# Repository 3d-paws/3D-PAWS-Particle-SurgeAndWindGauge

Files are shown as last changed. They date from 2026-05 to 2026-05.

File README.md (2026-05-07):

# Storm Surge Wind Gauge (SSWG)

### Storm Surge

The station used the below storm surge calculation.

#### 3 minute water level average
181 one-second water level samples are centered at (0,6,12,18,24,30,36,42,48,54). These samples are averaged, 
a three standard deviation outlier rejection test applied, 
the mean and standard deviation are recalculated and reported along with the number of outliers.

We can use the 181 observations to capture the mean and standard deviation and then multiply the value by 3. 

Reference:  https://tidesandcurrents.noaa.gov/publications/CO-OPS_Measurement_Spec.pdf

Add 90 seconds after each (0,6,12,18,24,30,36,42,48,54) sample period for the reported time.

#### To calculate the standard deviation of those numbers:

 - Work out the Mean (the simple average of the numbers)
 - Then for each number: subtract the Mean and square the result.
 - Then work out the mean of those squared differences.
 - Take the square root of that and we are done!

#### A sigma value is a statistical term otherwise known as a standard deviation. The three-sigma process:

 - 1 Calculate the mean
 - 2 Calculate the standard deviation
 - 3 Multiply the standard deviation by 3
 - 4 Subtract the product in step 3 from the mean

#### Distance Sensors

 - The 5-meter sensors (MB7360, MB7369, MB7380, and MB7389) use a scale factor of (Vcc/5120) per 1-mm. Particle 12bit resolution (0-4095),  Sensor has a resolution of 0 - 5119mm,  Each unit of the 0-4095 resolution is 1.25mm

 - The 10-meter sensors (MB7363, MB7366, MB7383, and MB7386) use a scale factor of (Vcc/10240) per 1-mm. Particle 12bit resolution (0-4095),  Sensor has a resolution of 0 - 10239mm,  Each unit of the 0-4095 resolution is 2.5mm

### Wind Support

Wind is enabled by default. Meaning you should add a AS5600 for direction readings. Or disable able wind with NOWIND.TXT file.

### Sensor Support
| Sensor Model | Type | Description | Company URL |
|---|---|---|---|
| Adafruit HTU21DF | Temp/Humidity | Digital I2C sensor, ±2% RH, ±0.3°C, compact, low power. | [Adafruit HTU21DF](https://www.adafruit.com/product/1899) |
| Adafruit MCP9808 | Temperature | High-precision digital temp sensor, ±0.25°C, 2.7-5.5V, I2C. | [Adafruit MCP9808](https://www.adafruit.com/product/1782) |
| Adafruit BME280 | Temp/Humidity/Pressure  | Measures temp, humidity, pressure, I2C/SPI, -40 to +85°C, 0-100% RH, 1.8-5V. | [Adafruit BME280](https://www.adafruit.com/product/2652) |
| Adafruit BMP280 | Temp/Pressure | Measures pressure (300–1100 hPa), temperature, I2C/SPI, small, low-power. | [Adafruit BMP280](https://www.adafruit.com/product/2651) |
| Adafruit BMP3XX | Temp/Pressure | Gen3 barometric, high-precision, ±0.5m alt., I2C/SPI. | [BMP388/BMP3XX](https://shop.pimoroni.com/en-us/products/adafruit-bmp388-precision-barometric-pressure-and-altimeter) |
| Adafruit_BMP5xx | Temp/Pressure | BMP5xx series (BMP581) is a high-precision barometric pressure sensors from Bosch Sensortec | [Adafruit BMP5xx](hhttps://www.adafruit.com/product/6407) |
| Adafruit SHT31 | Temp/Humidity | High accuracy, ±2% RH, ±0.3°C, I2C, fast response, 2.4–5.5V. | [Adafruit SHT31](https://www.adafruit.com/product/2857) |
| Adafruit_SHT4x | Temp/Humidity | Adafruit Sensirion SHT45 Precision Temp & Humidity with PTFE | [Adafruit SHT45](https://www.adafruit.com/product/5665) |
| Adafruit PM25AQI | PM2.5 Air Quality | Measures particulate (0.3–10um), I2C (fixed 0x12), 0-500μg/m³ range, 5V. | [PM25AQI](https://www.adafruit.com/product/4632) |
| AS5600L | Magnetic Encoder | Same as AS5600, but designed for integration in new designs (ex: Particle Muon). | [SS451A Datasheet](https://sensing.honeywell.com) |
| SS451A (Anemometer) | Hall Effect Switch | Used as wind anemometer sensor (rotation detection). | [TMP112A Sensor](https://www.ti.com/product/TMP112A) |
| Adafruit VEML7700 | Ambient Light | Precise lux (0–120klux), I2C, auto-range, digital output, 3.3/5V. | [Adafruit VEML7700](https://www.adafruit.com/product/4162)  |
| Adafruit SI1145 | Light/UV/Proximity | I2C, measures visible, IR, and digital UV index, 3-5V. | [Adafruit SI1145](https://www.adafruit.com/product/1777) |
| MB7360, MB7369, MB7380, MB7389| 5m Distance | Maxbotix Ultrasonic Distance Sensor | [Maxbotix](https://maxbotix.com/products) |
| MB7363, MB7366, MB7383, MB7386| 10m Distance | Maxbotix Ultrasonic Distance Sensor | [Maxbotix](https://maxbotix.com/products) |

### Derived Observations
- Heat Index (hi) is reported if sensor SHT_1 exists.
- Mean Sea Level Pressure (mlsp) if station elevation is set "ELEV.TXT" and station is configured with a SHT and BMP sensors.

### Sensor Tag Name Assignments for BMPxxx, BMExxx SHT31, SHT45, HDC302x
These sensors have multiple address options.
<pre>
bmx  0x77 BMP280, BME280, BMP388, BMP390    Default Address for the BMP
bmx  0x76 BMP280, BME280, BMP388, BMP390    Default Address for the BME

sht3 0x44 Default
sht3 0x45 with jumper  

sht4 0x44 Default and only address

b58  0x47 default      BMP581
b58  0x46 with jumper  BMP581
</pre>
When multiple sensor combinations are used with dynamic discovery, tag name assignment can become complex. The following rules define how tag names are assigned.

For BMP280, BME280, BMP388, and BMP390 sensors, detection is prioritized first. If one of these sensors is found at I2C address 0x77, it is assigned the tag bx1 (where x represents p, t, or h). If found at address 0x76, it is assigned bx2.

For the BMP581 sensor, assignment depends on availability. If a BMP581 is found at address 0x46 and bx1 is not already assigned, it becomes bx1. Otherwise, if bx2 is not assigned, it becomes bx2. If both bx1 and bx2 are already assigned, it becomes bx3. The same logic applies to address 0x47, with the next available tag being bx4 if bx3 is already in use.

For SHT sensors (SHT31 or SHT45), assignment depends on address priority. If a sensor is found at address 0x44, it is assigned st1 and sh1. If no sensor is present at 0x44 but an SHT31 is found at 0x45, it is assigned st1 and sh1. If a sensor is already present at 0x44, then an SHT31 at 0x45 is assigned st2 and sh2.

### DoAction Functions on Particle Cloud Console

On the view device screen on the Particle Console there is a FUNCTIONS area at the lower right. This is used to send commands to the online device.

- REBOOT - Reboot device. Toggle pin A0. If no relay/watchdog is connected to A0, then a soft boot on the Particle board is performed.
- INFO - Trigger station to send station information                . Event type "INFO".
- 5MDIST - Configure 5m Sensor. Creates file 5MDIST.TXT. Value read from pin A4 is multiplied by 1.25mm.
- 10MDIST - Configure 10m Sensor. Removes file 5MDIST.TXT. Value read from pin A4 is multiplied by 2.5mm. (Default)
- SETELEV:xxxx - Set station elevation. Replace xxxx with elevation in meters. Creates file ELEV.TXT
- NOWIND - Disable wind. Created file NOWIND.TXT.
- DOWIND - Removes file NOWIND.TXT if it exists, you should rebot after this.
- OP2RAW - Enable OP2 pin for raw readings. Creates OP2RAW.TXT.
- OP2VBV - Enable OP2 pin for reading Voltaic Battery Voltage.  Creates OP2VBV.TXT.
- OP2CLR - Disable OP2 pin configurations. Removes OP2RAW.TXT OP2VBV.TXT files.

### File and Directory Overview

| File/Directory | Purpose |
|---|---|
| `/OBS/` | Directory containing observation files. |
| `/OBS/20251201.LOG` | Daily observation file in JSON format (one file per day). |
| `/N2SOBS.TXT` | "Need to Send" file storing unsent observations. Resets if larger than specified size.  |
| `/SIM.TXT` | Support file for third-party SIM configurations. |
| `/WIFI.TXT` | Stores WiFi configuration information for Argon WiFi and Muon boards. |
| `/INFO.TXT` | Station info file. Overwritten with every INFO call. |
| `/ELEV.TXT` | Station elevation. File contents is elevation in meters. |
| `/NOWIND.TXT` | Disable wind. |
| `/OP2RAW.TXT` | Configures OP2 for raw readings (avg. 5 samples spaced 10ms).|
| `/OP2VBV.TXT` | Configures OP2 for reading Voltaic Battery Voltage.|

### Argon WiFi Support

At the top level of the SD card make a file called WIFI.TXT. Add one line to the file. This line has 3 items that are comma separated.
Example

 - AuthType,ssid,password
 
Where AuthType is one of these keywords (WEP WPA WPA2 UNSEC). A blank password is supported for UNSEC

### Boron 3rd Party Sim Support

At the top level of the SD card make a file called SIM.TXT. The first line of the file is read for the below patterns.

 - INTERNAL
 - AUP epc.tmobile.com username passwd
 - UP username password
 - APN epc.tmobile.com

After power on the file is read. The configuration is set in non volatile memory. Then the file is renamed to SIMOLD.TXT, so we don't do this on next boot. Reboot necessary.

### Argon and Boron Board Pin Mappings

| Pin  | Function / Usage |
|---|---|
|D8 | Serial Console (Ground Pin to Enable) - Not on Grove Shield |
|D7 | On Board LED - Blinks when console connection needed|
|D6 | Future Reserved for Lora IRQ - Not on Grove Shield|
|D5 | SD Card Chip Select|
|D4 | SPI1 MSIO - Future Reserved for LoRa|
|D3 | SPI1 MOSI - Future Reserved for LoRa|
|D2 | SPI1 SCK  - Future Reserved for LoRa|
|D1 | I2C SCL|
|D0 | I2C SDA|
|A0 | WatchDog Monitor/Relay Reset Trigger|
|A1 | WatchDog Monitor Heartbeat|
|A2 | Wind Speed IRQ|
|A3 | Not in use|
|A4 | Distance Sensor|
|A5 | OPTION 2 Pin - Do Actions: OP2RAW, OP2VBV, OP2CLR |
|D13  | SPIO CLK SD Card|
|D12  | SPI0 MOSI  SD Card|
|D11  | SPI0 MISO  SD Card|
|D10  | UART1 RX - Future Reserved for LoRa CS|
|D9 | UART1 TX - Future Reserved for LoRa RESET|

### System Health Bits
A register is maintained where its individual bits correspond to various state information and sensor state. This register is reported in each observation as a decimal number with tag id "hth". Many of the below bits will be set at initialization. Then cleared after the first observation is made after startup. 
<div style="overflow:auto; white-space:pre; font-family: monospace; font-size: 8px; line-height: 1.5; height: 120px; border: 1px solid black; padding: 10px;">
<pre>
#define SSB_PWRON           0x1       // Set at power on, but cleared after first observation
#define SSB_SD              0x2       // Set if SD missing at boot or other SD related issues
#define SSB_N2S             0x4       // Set when Need to Send observations exist
#define SSB_FROM_N2S        0x8       // Set in transmitted N2S observation when finally transmitted
#define SSB_RTC             0x10      // Set if RTC missing at boot
</pre>
</div>

### Particle Publish Event Name "SS" (Storm Surge)
<div style="overflow:auto; white-space:pre; font-family: monospace; font-size: 8px; line-height: 1.5; height: 650px; border: 1px solid black; padding: 10px;">
<pre>
Event Name: SS

Event Variables:
at     timestamp
wl     water_level
wld    water_level_stdev
wlo    water_level_outliers
wlm    water_level_mean
wlr    water_level_raw
ws     wind_speed
wd     wind_direction
wg     wind_gust
wgd    wind_gust_direction
bp1    BME280,BMP280,BMP3XX,BMP4XX Pressure
bt1    BME280,BMP280,BMP3XX,BMP4XX Temperature
bh1    BME280,BMP280,BMP3XX,BMP4XX Humidity
bp2    BME280,BMP280,BMP3XX,BMP4XX Pressure
bt2    BME280,BMP280,BMP3XX,BMP4XX Temperature
bh2    BME280,BMP280,BMP3XX,BMP4XX Humidity
bp3    BMP4XX Pressure
bt3    BMP4XX Temperature
bh3    BMP4XX Humidity
bp4    BMP4XX Pressure
bt4    BMP4XX Temperature
bh4    BMP4XX Humidity
hh1    htu_humid
ht1    htu_temp
sh1    sht_humid
st1    sht_temp
sh2    sht_humid
st2    sht_temp
mt1    mcp_temp
mt2    mcp_temp
hi     heat index
sv1    SI1145 VIS
si1    SI1145 IR
su1    SI1145 UV
vlx    VEML7700 LUX
mlsp   mean sea level pressure
vbv    voltaic battery voltage
vpc    voltaic percent charge
op2r   option 2 raw reading
bcs    Battery Charger Status
bpc    Battery Percent Charge
cfr    Charger Fault Register
css    Cell Signal Strength
hth    Health 16bits - See System Status Bits in below define statements

Battery Charger Status
0 = BATTERY_STATE_UNKNOWN
1 = BATTERY_STATE_NOT_CHARGING
2 = BATTERY_STATE_CHARGING
3 = BATTERY_STATE_CHARGED
4 = BATTERY_STATE_DISCHARGING
5 = BATTERY_STATE_FAULT
6 = BATTERY_STATE_DISCONNECTED
</pre>
</div>
# Serial Monitor

Adding a jumper wire between Particle pin D8 (Boron & Argon), A2 (Muon) and ground will enable serial text output on the USB port at boot time.

A serial monitor from Arduino's IDE can be used. TIP: With the Arduino serial monitor. Select "Both NL & CR" on the pull down menu at the bottom.  On a Mac with Visual Studio installed with Particle's Development Environment; the shell command "particle serial monitor" can be used.

Upon Particle board boot with the jumper wire connected, software will wait 60 seconds for you to connect the serial monitor. Flashing the board led.  After 60 seconds the software will continue the boot process. Below is an example of what you might see as the software initializes and discovers connected devices.

If the jumper remains connected after boot. You will enter the Station Monitor. The station monitor will run for 30 minutes. Removing the jumper will exit you from the station monitor.

### Station Information - (Particle Message type "INFO")
At boot the station will send a event message of type "INFO" to Particle. This message contains configuration and status information. You can also request an INFO event message to be sent from the device via DoAction Function on the Particle Console. Use keyword "INFO". Every INFO execution will create/rewrite file INFO.TXT with INFO information. The information reported will vary based on the board type (Boron, Argon, Muon). Below are examples.

INFO event message from a Boron
<div style="overflow:auto; white-space:pre; font-family: monospace; font-size: 8px; line-height: 1.5; height: 425px; border: 1px solid black; padding: 10px;">
<pre>
{
"devid":"e00fce68bde8f63590a3b118"
"devos":"6.4.1"
"freemem":82440
"uptime":143
"board":"boron"
"at":"2026-05-07T21:39:24"
"ver":"SSWG-20260507v11"
"hth":1
"rr":"120-0"
"obsi":"6m"
"obsti":"6m"
"drct":79200
"n2s":"NF"
"ps":"USB_HOST"
"bcs":"MISSING"
"bpc":-1
"css":52.4987
"csq":12.4987
"imsi":"234103519249568"
"actsim":"INTERNAL"
"op1":"DIST 10M(a4)"
"op2":"VBV(A5)"
"elev":1560
"sensors":"BMX1(BMP390),SHT45(44-E1856B9),SHT31(45-118DF311),BMP581(47),MCP1,AS5600,HI,MSLP,WS(A2)"
"rtc":"OK"
"oled":"32"
"scepin":"DISABLED"
"sce":"TRUE"
}
</pre>
</div>

### WatchDog Board Support
The WatchDog is a external device that can turn off power to your weather station's microcontroller and sensors. Power remains off for 10 seconds. Ways the WatchDog can be triggered to turn off power
- If the station microcontroller's heartbeat pulse stops for 5 minutes.
- If a trigger pulse is sent from the weather station's microcontroller to the WatchDog.
- Weather station software does a daily reboot and will send a trigger pulse.
- Particle Console for this device can send a DoAction function "REBOOT" down to the weather station's microcontroller. To send the trigger pulse.

For more information see GutHub Site [3d-paws/3D-PAWS-WatchDog](https://github.com/3d-paws/3D-PAWS-WatchDog/blob/master/README.md).

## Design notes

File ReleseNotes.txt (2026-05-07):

=================================================================================================================
ReleseNotes.txt
=================================================================================================================

=================================================================================================================
Version 11
=================================================================================================================
Added DoAction NOWIND (Default) & DOWIND
Now following the NOAA standard for Distance of 181s
OP2 support added for OP2RAW | OP2VBV (Voltaic) | OP2CLR
Added BMP581 and SHT45 sensor support
Updated the handling of the BMx sensors.
Removed support for HIH sensor
Bug Fix SETELEV 

=================================================================================================================
Version 10
=================================================================================================================
Library Update Notes

Used Arduino to pull down the libraries
Renamed the folders removing _Library 
Created src directory under each
Moved .h .c and .cpp to src directory
Made changes as needed. See below.

Cleared out prior compiles 
  rm -rf ~/.particle/toolchains/deviceOS/6.3.3/build/target/user/platform-13-m/3D-PAWS-Particle-SurgeAndWindGauge
  rm -rf ~/Documents/Particle/3D-PAWS-Particle-SurgeAndWindGauge/target/6.3.3

Updated the project.properties in the main folder

==============================================================================================
Adafruit_BME280/library.properties:version=2.1.4     2.3.0
Adafruit_BMP280/library.properties:version=2.3.0     2.6.8
Adafruit_BMP3XX/library.properties:version=2.1.1     2.1.6
Adafruit_BusIO/library.properties:version=1.8.2      1.17.3
Adafruit_GFX/library.properties:version=1.10.10      1.12.4

Adafruit_Sensor/library.properties:version=1.1.4     1.11.5    Adafruit Unified Sensor
  vi Adafruit_Sensor.cpp. added #ifdef NOWAY around the function in the .cpp

Adafruit_HTU21DF/library.properties:version=1.1.0    1.1.2
Adafruit_MCP9808/library.properties:version=2.0.0    2.0.2

Adafruit_SHT31/library.properties:version=2.2.0      2.2.2
  cp Adafruit_SHT31.h Adafruit_SHT31.h-org
  < // ICDP Removed for Particle
  < // extern TwoWire Wire; /**< Forward declarations of Wire for board/variant combinations that don't have a default 'Wire' */
  ---
  > extern TwoWire Wire; /**< Forward declarations of Wire for board/variant
  >                         combinations that don't have a default 'Wire' */

Adafruit_SI1145/library.properties:version=1.1.1     1.2.2
Adafruit_SSD1306/library.properties:version=2.4.6    2.5.15
Adafruit_VEML7700/library.properties:version=2.1.2   2.1.6

RTClib/library.properties:version=1.13.0             2.1.4
 add #define PCF8523_ADDRESS 0x68       // I2C address for PCF8523   in time.h

SdFat/library.properties:version=1.0.16              2.3.0

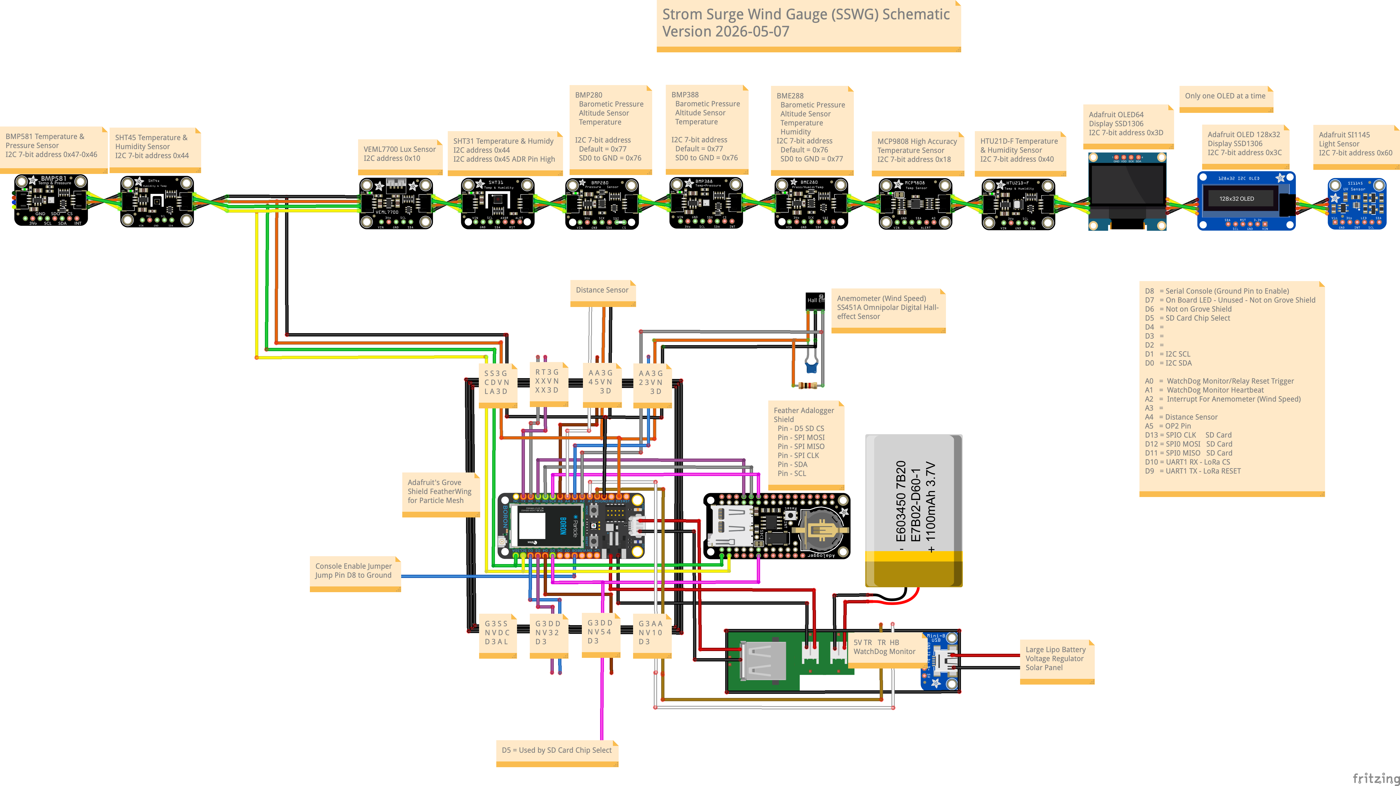
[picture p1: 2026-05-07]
Fritzing/SSGAWG-v20260507.png

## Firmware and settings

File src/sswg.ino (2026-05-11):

PRODUCT_VERSION(13);
#define COPYRIGHT "Copyright [2025] [University Corporation for Atmospheric Research]"
#define VERSION_INFO "SSWG-20260511v13"

/*
 *======================================================================================================================
 * StormSurgeAndWindGauge (SSWG)
 *   Board Type : Particle BoronLTE / Particle Argon
 *   Description: Storm Surge Gauge follows NOAA's method to determine water level 
 *   Author: Robert Bubon
 *   Date:  2021-07-28 RJB Based on SSG and Full station's Wind
 *          2021-08-02 RJB Take 5 samples and use the median for the reading 
 *          2021-10-07 RJB Production Release to Particle V1
 *          2021-11-12 RJB Version 2 
 *                         Battery Charger Fault Register, Variable name "cfr" Added
 *                         Adafruit BMP388 Support Added
 *                         Remote Reboot Added
 *                         PMIC was changed to match other code, low battery shutdown conditional changed
 *                         Bug: msgbuf 256 was too small increased to 1024
 *                         Added CloudDisconnectOptions().graceful(true).timeout(5s)
 *          2023-01-22 RJB Bug HTU had humidity and Temp flipped
 *          2023-07-30 RJB Fixed bug to get RTC updated from network time
 *          2023-08-22 RJB Moved from 3.0.0 Firmware to 4.0.2
 *                         Update BMX sensor code
 *                         Added Min Max Quality Controls to sensor values
 *                         Added WITH_ACK to Particle Publish
 *                         Moved Wind Speed pin from D6 to A2
 *                         Added EEPROM support for N2S position
 *                         Added support for Watchdog Monitor
 *                         Brought over output initialization code from FSAC - now support 8 line oleds
 *                         Added MCP and SHT sensor support
 *          2023-08-28 RJB Bug Fix was sending sht for mcp reading
 *          2023-09-12 RJB Hardened Time handeling
 * 
 *          Version 5 Released on 2024-05-21
 *          2024-02-23 RJB At boot look for a file "5MDIST.TXT" on the SD.  
 *                         If file exists then we multiply by 1.25. If no file, then we multiply by 2.5 for the 10m Sensor. 
 *                         Particle console will support 3 DoAction commands, "REBOOT", "10MDIST", "5MDIST". 
 *          2024-04-30 RJB Added Argon support
 *                         Added 22hr reboot
 *                         Added 3rd party sim support
 *                         Moved SCE Pin from A4 to D8
 *                         Improved Station Monitor output
 *          2024-05-20 RJB Improved Station Monitor output
 *                         Dynamic display support added.
 *                         SHT, HIH, LUX, SI1145 sensor support added 
 *                         Updated I2C_Check_Sensors()
 * 
 *          Version 7 Released on 2024-12-18
 *          2024-06-23 RJB Added Copyright
 *          2024-07-11 RJB Broke code down to #include files
 *          2024-07-23 RJB Bug 5MDIST cmd was setting od_adjustment to 8.
 *                         Also set odg_adjustment after adding/removing 5MDIST.TXT file
 *          2024-09-09 RJB Tweek Station Monitor added 5M 10M to output
 *          2024-09-11 RJB Wind Initialization and Station Monitor changed to provide
 *                         better output about wind speed and direction.
 *                         When setting SIM to INTERNAL we now set changed = true to
 *                         report success and reboot message.
 *          2024-09-14 RJB Modified WiFi Support for UNSEC allowing no password Ex:  "UNSEC,ssid,"
 *          2024-11-05 RJB Discovered BMP390 first pressure reading is bad. Added read pressure to bmx_initialize()
 *                         Bug fixes for 2nd BMP sensor in bmx_initialize() using first sensor data structure
 *                         Now will only send humidity if bmx sensor supports it.
 *          2024-12-18 RJB Compiled with deviceOS6.1.1
 * 
 *          Version 8 Released on 2024-12-22
 *          2024-12-19 RJB Updated Adafruit_VEML7700 library to 2.1.6
 *          2024-12-22 RJB Added INFO support feature
 *                         Removed unnecessary globals and functions not used
 *                            bool ParticleConnecting = false; 
 *                            int StartedConnecting = 0;
 *                            bool PostedResults;
 *                            bool firmwareUpdateInProgress = false;
 *                            firmwareUpdateHandler()
 * 
 *          Version 9 Released on 2025-11-12
 *          2025-04-08 RJB Removed the check for serial console in SimChangeCheck()
 *          2025-11-12 RJB Bug Fix SHT temp sensor was also reporting as humidity.
 *                         Updated the OS to 6.3.3
 * 
 *          Version 10 Released on 2025-12-03
 *          2025-11-19 RJB Code cleanup aka .cpp
 *                         Add MSLP support
 *                         Tweeked EEPROM_Valid()
 *                         VEML7700 lux now reports as vlx
 *                         variable od_ changed to dg_
 *                         DISTANCEGAUGE moved from A3 to A4 
 *                         Added obtaining imsi and logging via INFO
 *                         Updated all the libraries.
 *                         See ReleaseNotes.txt file
 *                         Updated to ParticleOS 6.3.4
 * 
 *          Version 11 & 12 Released on 2026-05-07 - Skipped had a bug in as5600 being set true by default
 * 
 *          Version 13 Released on 2026-05-11
 *          2026-05-11 RJB Updated to ParticleOS 6.4.1
 *                         Added DoAction NOWIND (Default) & DOWIND
 *                         Now following the NOAA standard for Distance of 181s
 *                         OP1 will always be Distance. OP2 = OP2RAW | OP2VBV (Voltaic) | OP2CLR
 *                         Added BMP581 and SHT45 sensor support
 *                         Updated the handling of the BMx sensors.
 *                         Removed support for HIH sensor
 *                         Bug Fix SETELEV
 *                                   
 *  https://tidesandcurrents.noaa.gov/publications/CO-OPS_Measurement_Spec.pdf
 *  Air acoustic sensor mounted in protective well
 *   181 one-second water level samples centered on each tenth of an hour are averaged, a three standard deviation 
 *   outlier rejection test applied, the mean and standard deviation are recalculated and reported along with 
 *   the number of outliers. (3 minute water level average).
 *
 * NOTES:
 * When there is a successful transmission of an observation any need to send obersavations will be sent. 
 * On transmit a failure of these need to send observations, processing is stopped and the file is deleted.
 * 
 * Gauge Calibration
 * Adding serial console jumper after boot will cause gauge to be read every 1 second and value printed.
 * Removing serial console jumper will resume normal operation
 * 
 * Requires Library
 *  SdFat                   by Bill Greiman
 *  RTCLibrary
 *  Adafruit_SSD1306_RK     I2C ADDRESS 0x3C
 *  Adafruit_BM(PE)280      I2C ADDRESS 0x77  (SD0 to GND = 0x76)
 *  adafruit-htu21df        I2C ADDRESS 0x40
 *  Adafruit_BMP3XX         I2C ADDRESS 0x77 and (SD0 to GND = 0x76)
 *  Adafruit_SHT31          I2C ADDRESS 0x44 and 0x45 when ADR Pin High
 *  Adafruit_MCP9808        I2C ADDRESS 0x18
 * 
 * System.batteryState()
 *  0 = BATTERY_STATE_UNKNOWN
 *  1 = BATTERY_STATE_NOT_CHARGING
 *  2 = BATTERY_STATE_CHARGING
 *  3 = BATTERY_STATE_CHARGED
 *  4 = BATTERY_STATE_DISCHARGING
 *  5 = BATTERY_STATE_FAULT
 *  6 = BATTERY_STATE_DISCONNECTED
 * 
 * Publish to Particle
 *  Event Name: SS
 *  Event Variables:
 *   at     timestamp
 *   wl     water_level
 *   wld    water_level_stdev
 *   wlo    water_level_outliers
 *   wlm    water_level_mean
 *   wlr    water_level_raw
 *   ws     wind_speed
 *   wd     wind_direction
 *   wg     wind_gust
 *   wgd    wind_gust_direction
 *   bp1    BME280,BMP280,BMP3XX,BMP4XX Pressure
 *   bt1    BME280,BMP280,BMP3XX,BMP4XX Temperature
 *   bh1    BME280,BMP280,BMP3XX,BMP4XX Humidity 
 *   bp2    BME280,BMP280,BMP3XX,BMP4XX Pressure
 *   bt2    BME280,BMP280,BMP3XX,BMP4XX Temperature
 *   bh2    BME280,BMP280,BMP3XX,BMP4XX Humidity
 *   bp3    BMP4XX Pressure
 *   bt3    BMP4XX Temperature
 *   bh3    BMP4XX Humidity
 *   bp4    BMP4XX Pressure
 *   bt4    BMP4XX Temperature
 *   bh4    BMP4XX Humidity
 *   hh1    htu_humid
 *   ht1    htu_temp
 *   sh1    sht_humid
 *   st1    sht_temp
 *   sh2    sht_humid
 *   st2    sht_temp
 *   mt1    mcp_temp
 *   mt2    mcp_temp
 *   hi     heat index
 *   mlsp   mean sea level pressure
 *   bcs    Battery Charger Status
 *   bpc    Battery Percent Charge
 *   cfr    Charger Fault Register
 *   css    Cell Signal Strength
 *   hth    Health 16bits - See System Status Bits in below define statements
 * 
 * 
 * ========================================================
 * Boron/Argon PIN Assignments
 * ========================================================
 * D8   = Serial Console (Ground Pin to Enable) - Not on Grove Shield
 * D7   = On Board LED - Blinks when console connection needed
 * D6   = Future Reserved for Lora IRQ - Not on Grove Shield
 * D5   = SD Card Chip Select
 * D4   = SPI1 MSIO - Future Reserved for LoRa
 * D3   = SPI1 MOSI - Future Reserved for LoRa
 * D2   = SPI1 SCK  - Future Reserved for LoRa
 * D1   = I2C SCL
 * D0   = I2C SDA
 * 
 * A0   = WatchDog Monitor/Relay Reset Trigger
 * A1   = WatchDog Monitor Heartbeat
 * A2   = Wind Speed IRQ
 * A3   = Not in use
 * A4   = Distance Sensor
 * A5   = OPTION 2 Pin - Do Actions: OP2RAW, OP2VBV, OP2CLR 
 * D13  = SPIO CLK   SD Card
 * D12  = SPI0 MOSI  SD Card
 * D11  = SPI0 MISO  SD Card
 * D10  = UART1 RX - Future Reserved for LoRa CS
 * D9   = UART1 TX - Future Reserved for LoRa RESET
 * 
 * AN002 Device Powerdown
 * https://support.particle.io/hc/en-us/articles/360044252554?input_string=how+to+handle+low+battery+and+recovery
 * 
 * Distance Sensors
 * The 5-meter sensors (MB7360, MB7369, MB7380, and MB7389) use a scale factor of (Vcc/5120) per 1-mm.
 * Particle 12bit resolution (0-4095),  Sensor has a resolution of 0 - 5119mm,  Each unit of the 0-4095 resolution is 1.25mm
 * 
 * The 10-meter sensors (MB7363, MB7366, MB7383, and MB7386) use a scale factor of (Vcc/10240) per 1-mm.
 * Particle 12bit resolution (0-4095),  Sensor has a resolution of 0 - 10239mm,  Each unit of the 0-4095 resolution is 2.5mm
 * 
 * NOTE: Compile Issues
 * If you have compile issues like multiple definations of functions then you need to clean the compile directory out
 *    ~/.particle/toolchains/deviceOS/2.0.1/build/target/user/...
 * 
 * ========================================================
 * Support for 3rd Party Sim 
 * ========================================================
 *   SEE https://support.particle.io/hc/en-us/articles/360039741113-Using-3rd-party-SIM-cards
 *   SEE https://docs.particle.io/cards/firmware/cellular/setcredentials/
 *   Logic
 *     Output how sim is configured (internal or external)
 *     If console is enabled and SD found and SIM.TXT exists at the top level of SD card
 *       Read 1st line from SIM.TXT. Parse line for one of the below patterns
 *        INTERNAL
 *        AUP epc.tmobile.com username passwd
 *        UP username password
 *        APN epc.tmobile.com
 *      Perform appropriate actions to set sim
 *      Rename file to SIMOLD.TXT, so we don't do this on next boot
 *      Output notification to user to reboot then flash board led forever
 *
 * ========================================================
 * Support for Argon WiFi Boards
 * ========================================================
 * At the top level of the SD card make a file called WIFI.TXT
 * Add one line to the file
 * This line has 3 items that are comma separated Example
 * 
 * AuthType,ssid,password
 * 
 * Where AuthType is one of these keywords (WEP WPA WPA2 UNSEC)
 * Blank password is supported for UNSEC
 * ======================================================================================================================
 */

/* 
 *=======================================================================================================================
 * Local Includes
 *=======================================================================================================================
 */
#include "include/ssbits.h"         // System Status Bits
#include "include/qc.h"             // Quality Control Min and Max Sensor Values on Surface of the Earth
#include "include/support.h"        // Support Functions
#include "include/sdcard.h"         // SD Card Functions
#include "include/cf.h"             // Configuration File Variables
#include "include/eeprom.h"         // EEPROM Functions
#include "include/output.h"         // Serial and OLED Output Functions
#include "include/wrda.h"           // Wind Rain Distance Air Functions
#include "include/time.h"           // Time Management Functions
#include "include/ps.h"             // Particle Support Functions
#include "include/sensors_i2c_44_47.h" // Handle i2c Sensors in this address range
#include "include/sensors.h"        // I2C Based Sensor Functions
#include "include/info.h"           // Station Information Functions
#include "include/statmon.h"        // Station Monitor Functions
#include "include/obs.h"            // Observation Functions
#include "include/main.h"

/*
 * ======================================================================================================================
 * Variables and Data Structures 
 * =======================================================================================================================
 */
char versioninfo[sizeof(VERSION_INFO)];  // allocate enough space including null terminator
char msgbuf[MAX_MSGBUF_SIZE]; // Used to hold messages
char *msgp;                   // Pointer to message text
char Buffer32Bytes[32];       // General storage
int  LED_PIN = D7;            // Built in LED
bool JustPoweredOn = true;         // Used to clear SystemStatusBits set during power on device discovery
uint64_t lastOBS = 0;         // time of next observation
int countdown = 1800;         // Exit calibration mode when reaches 0 - protects against burnt out pin or forgotten jumper
uint64_t LastTimeUpdate = 0;
int  cf_reboot_countdown_timer = 79200; // There is overhead transmitting data so take off 2 hours from 86400s                                        // Set to 0 to disable feature
int DailyRebootCountDownTimer;
bool SendSystemInformation = true; // Send System Information to Particle Cloud. True means we will send at boot.


#if PLATFORM_ID == PLATFORM_BORON
/*
 * ======================================================================================================================
 *  Power Management IC (bq24195)
 * ======================================================================================================================
 */
PMIC pmic;
#endif

/*
 * ======================================================================================================================
 *  Observation Timing
 *   Check current time to find which of the 10 obs periods we are in.
 *   If last_obs_time is not in this period, do an observerion and update the last_obs_time
 *   Report times 0,6,12,18,24,30,36,42,48,54. Add 90s after each to get below report times
 * ======================================================================================================================
 */
struct {
  int    sath[10]          = { 90, 450, 810, 1170, 1530, 1890, 2250, 2610, 2790, 3330};  // Seconds After The Hour
  time_t last_obs_time[10] = { 0, 0, 0, 0, 0, 0, 0, 0, 0, 0};
} OBS_Period;

/*
 * ======================================================================================================================
 * HeartBeat() - Burns 250 ms 
 * ======================================================================================================================
 */
void HeartBeat() {
  digitalWrite(HEARTBEAT_PIN, HIGH);
  delay(250);
  digitalWrite(HEARTBEAT_PIN, LOW);
}
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
void loop() {
  [[maybe_unused]] uint64_t LastConnectCheckTime = 0;
  static bool FirstParticleConnect = true;

  // If Serial Console Pin LOW then call StationMonitor()
  // Used for calibrating Stream Gauge at Installation
  // Only stay in this mode for countdown seconds, this protects against burnt out pin or forgotten jumper
  if (countdown && digitalRead(SCE_PIN) == LOW) {
    StationMonitor();
    countdown--; // Exit out if we forget to remove the jumper
  }
  else { // Normal Operation - Main Work
    // This will be invalid if the RTC was bad at poweron and we have not connected to Cell network
    // Upon connection to cell network system Time is set and this becomes valid
    if (Time.isValid()) {  

      // Set RTC from Cell network time.
      RTC_UpdateCheck();

      if (!eeprom_valid) {
        // We now a a valid clock so we can initialize the EEPROM
        EEPROM_Initialize();
      }

      if (SendSystemInformation && Particle.connected()) {
        INFO_Do(); // Function sets SendSystemInformation back to false.
      }

      // See if Time to Make Observation
      if (OBS_TimeCheck()) {
        // We take obs 90s afer each observertion period. doe for 0m->0m+90s 1m30s, 6m->6m+90s 7m30s... 
        // The distance buffer is 181 buckets.  We sample every second.

        OBS_Do(); // If Particle connected we save OBS to N2S

        // Shutoff System Status Bits related to initialization after we have logged first observation 
        JPO_ClearBits();
      }

      if (Particle.connected()) { 
        // Do some work
        LastConnectCheckTime = System.millis();
        if (FirstParticleConnect) {
          Output ("Connected");
          FirstParticleConnect = false;
        }
      }
#if PLATFORM_ID == PLATFORM_ARGON
      // See if it's been an hour without a network connection and transmission of data
      // With Argon WiFi we have seen it stuck in Breathing Green - Trying to connect
      else if (System.millis() - LastConnectCheckTime > (3600 * 1000)) {  
        // Been too long with out a network connection, lets reboot
        Output("1HR W/O NW: Rebooting");
        delay(5000);
        System.reset();
      }
#endif
    }
    else {
      stc_timestamp();
      Output(timestamp);
      Output("ERR: No Clock");
      delay (DELAY_NO_RTC);
    }

    // Reboot Boot Every 22+ hours - Not using time but a loop counter.
    if ((cf_reboot_countdown_timer>0) && (--DailyRebootCountDownTimer<=0)) {
      Output ("Daily Reboot");

      delay(1000);

      // Lets not rip the rug out from the modem. Do a graceful shutdown.
      Particle.disconnect();
      waitFor(Particle.disconnected, 1000);  // Returns true when disconnected from the Cloud.

 #if PLATFORM_ID == PLATFORM_BORON     
      // Be kind to the cell modem and try to shut it down
      Cellular.disconnect();
      delay(1000);
      Cellular.off();
#endif

      Output("Rebooting");  
      delay(1000);
   
      DeviceReset();

      // We should never get here, but just incase 
      Output("I'm Alive! Why?");  

#if PLATFORM_ID == PLATFORM_BORON
		  Cellular.on();
      delay(1000);
#endif

		  Particle.connect();

      DailyRebootCountDownTimer = cf_reboot_countdown_timer; // Reset count incase reboot fails

      // We need to reinitialize our wind readings before we can move on.
      WindAndDistance_Fill();
    }

#if PLATFORM_ID == PLATFORM_BORON
    // Check if we are not connected to a charging source and our battery is at a low level. 
    // If so then power down the display and board. Wait for power to return.
    //
    // We do this at a high enough battery level to avoid the board from powering
    // itself down out of our control. The goal is to leave enough battery for the sensors to
    // chew on and still be able, when power returns, to charge the battery and transmit 
    // with out a current drop causing the board to reset or power down out of our control.

    // We are on battery and have 10% or less percent left then turnoff and wait for power to return
    if (!pmic.isPowerGood() && (System.batteryCharge() <= 10.0)) {

      if (Particle.connected()) {
        INFO_Do(); // Function sets SendSystemInformation back to false.
      }
      
      Output("Low Power!");

      // Disconnect from the cloud and power down the modem.
      Particle.disconnect();
      waitFor(Particle.disconnected, 1000);  // Returns true when disconnected from the Cloud.

      Cellular.disconnect();
      delay(1000);
      Cellular.off();

      Output("Powering Down");

      OLED_sleepDisplay();
      delay(5000);

      // Disabling the BATFET disconnects the battery from the PMIC. Since there
      // is no longer external power, this will turn off the device.
		  pmic.disableBATFET();

		  // This line should not be reached. When power is applied again, the device
		  // will cold boot starting with setup().

		  // However, there is a potential for power to be re-applied while we were in
		  // the process of shutting down so if we're still running, enable the BATFET
		  // again and reconnect to the cloud. Wait a bit before doing this so the
		  // device has time to actually power off.
		  delay(2000);

      OLED_wakeDisplay();   // May need to toggle the Display reset pin.
		  delay(2000);
		  Output("Power Re-applied");

		  pmic.enableBATFET();
		  Cellular.on();
		  Particle.connect();

      WindAndDistance_Fill();
    } // powerdown
#endif
  } // normal operation

  BackGroundWork();
} // loop

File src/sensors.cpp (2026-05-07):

/*
 * ======================================================================================================================
 *  sensors.cpp - I2C based sensors
 * ======================================================================================================================
 */
#include "include/qc.h"
#include "include/ssbits.h"
#include "include/output.h"
#include "include/support.h"
#include "include/main.h"
#include "include/cf.h"
#include "include/sensors_i2c_44_47.h"
#include "include/sensors.h"

/*
 * ======================================================================================================================
 * Variables and Data Structures
 * =======================================================================================================================
 */


Adafruit_BMP280 bmp1;
Adafruit_BMP280 bmp2;
Adafruit_BME280 bme1;
Adafruit_BME280 bme2;
Adafruit_BMP3XX bm31;
Adafruit_BMP3XX bm32;
byte BMX_1_chip_id = 0x00;
byte BMX_2_chip_id = 0x00;
bool BMX_1_exists = false;
bool BMX_2_exists = false;
byte BMX_1_type=BMX_TYPE_UNKNOWN;
byte BMX_2_type=BMX_TYPE_UNKNOWN;
const char *bmxtype[] = {"UNKN", "BMP280", "BME280", "BMP388", "BMP390"};

/*
 * ======================================================================================================================
 *  HTU21D-F - I2C - Humidity & Temp Sensor
 * ======================================================================================================================
 */
Adafruit_HTU21DF htu = Adafruit_HTU21DF();
bool HTU21DF_exists = false;

/*
 * ======================================================================================================================
 *  MCP9808 - I2C - Temperature sensor
 * ======================================================================================================================
 */
Adafruit_MCP9808 mcp1;
Adafruit_MCP9808 mcp2;
bool MCP_1_exists = false;
bool MCP_2_exists = false;


/*
 * ======================================================================================================================
 *  Si1145 - I2C - UV/IR/Visible Light Sensor
 * ======================================================================================================================
 */
Adafruit_SI1145 uv = Adafruit_SI1145();
bool SI1145_exists = false;
// When we do a read of all three and we get zeros. If these llast readings are not zero, we will reinitialize the
// chip. When does a reset on it and then read again.
float si_last_vis = 0.0;
float si_last_ir = 0.0;
float si_last_uv = 0.0;

/*
 * ======================================================================================================================
 *  VEML7700 - I2C - Lux Sensor
 * ======================================================================================================================
 */
Adafruit_VEML7700 veml = Adafruit_VEML7700();
bool VEML7700_exists = false;

/*
 * ======================================================================================================================
 *  Heat Index Temperature - Derived from Temperature and Humidity Sensors
 * ======================================================================================================================
 */
bool HI_exists = false;

/* 
 *=======================================================================================================================
 * MSLP - Mean sea level pressure 
 *=======================================================================================================================
 */
bool MSLP_exists = false;

/*
 * ======================================================================================================================
 * Fuction Definations
 * =======================================================================================================================
 */

/* 
 *=======================================================================================================================
 * get_Bosch_ChipID ()  -  Return what Bosch chip is at specified address
 *   Chip ID BMP280 = 0x58 temp, preasure           - I2C ADDRESS 0x77  (SD0 to GND = 0x76)  
 *   Chip ID BME280 = 0x60 temp, preasure, humidity - I2C ADDRESS 0x77  (SD0 to GND = 0x76)  Register 0xE0 = Reset
 *   Chip ID BMP388 = 0x50 temp, preasure           - I2C ADDRESS 0x77  (SD0 to GND = 0x76)
 *   Chip ID BMP390 = 0x60 temp, preasure           - I2C ADDRESS 0x77  (SD0 to GND = 0x76)
 *=======================================================================================================================
 */
byte get_Bosch_ChipID (byte address) {
  byte chip_id = 0;
  byte error;

  Output ("get_Bosch_ChipID()");
  // The i2c_scanner uses the return value of
  // the Write.endTransmisstion to see if
  // a device did acknowledge to the address.

  // Important! Need to check the 0x00 register first. Doing a 0x0D (not chip id loaction) on a bmp388 
  // will return a value that could match one of the IDs 

  // Check Register 0x00
  sprintf (msgbuf, "  I2C:%02X Reg:%02X", address, 0x00);
  Output (msgbuf);
  Wire.begin();
  Wire.beginTransmission(address);
  Wire.write(0x00);  // BM3 CHIPID REGISTER
  error = Wire.endTransmission();
    //  0:success
    //  1:data too long to fit in transmit buffer
    //  2:received NACK on transmit of address
    //  3:received NACK on transmit of data
    //  4:other error 
  if (error) {
    sprintf (msgbuf, "  ERR_ET:%d", error);
    Output (msgbuf);
  }
  else if (Wire.requestFrom(address, 1)) {  // Returns the number of bytes returned from the slave device 
    chip_id = Wire.read();
    if (chip_id == BMP280_CHIP_ID) { // 0x58
      sprintf (msgbuf, "  CHIPID:%02X BMP280", chip_id);
      Output (msgbuf);
      return (chip_id); // Found a Sensor!
    }
    else if (chip_id == BMP388_CHIP_ID) {  // 0x50
      sprintf (msgbuf, "  CHIPID:%02X BMP388", chip_id);
      Output (msgbuf);
      return (chip_id); // Found a Sensor!   
    }
    else if (chip_id == BME280_BMP390_CHIP_ID) {  // 0x60
      sprintf (msgbuf, "  CHIPID:%02X BME/390", chip_id);
      Output (msgbuf);
      return (chip_id); // Found a Sensor!   
    }
    else {
      sprintf (msgbuf, "  CHIPID:%02X InValid", chip_id);
      Output (msgbuf);      
    }
  }
  else {
    sprintf (msgbuf, "  ERR_RF:0");
    Output (msgbuf);
  }
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

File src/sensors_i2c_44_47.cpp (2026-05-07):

/*
 * ======================================================================================================================
 *  sensors_i2c_44_47.cpp - Discover I2C Sensors on addresses 0x44 to 0x47
 * ======================================================================================================================
 */
#include "include/qc.h"
#include "include/sensors.h"
#include "include/sensors_i2c_44_47.h"
#include "include/support.h"
#include "include/output.h"
#include "include/obs.h"
#include "include/main.h"

/*
 * ======================================================================================================================
 * Variables and Data Structures
 * =======================================================================================================================
 */
I2C_44_47_SENSOR_SLOT i2c_44_47_sensors[I2C_44_47_SENSOR_COUNT];

bool SHT_1_exists = false;
float sht1_humid = 0.0;
float sht1_temp = 0.0;


/*
 * ======================================================================================================================
 * Fuction Definations
 * =======================================================================================================================
 */

/*
 * ======================================================================================================================
 * readBytes()
 * =======================================================================================================================
 */
bool readBytes(uint8_t addr, uint8_t *buf, size_t len, uint16_t timeoutMs = 1000) {
  Wire.requestFrom(addr, (uint8_t)len);
  unsigned long start = millis();
  size_t i = 0;
  while (i < len && (millis() - start) < timeoutMs) {
    if (Wire.available()) {
      buf[i++] = Wire.read();
    }
  }
  return i == len;
}

/*
 * ======================================================================================================================
 * sht31_probe()
 * =======================================================================================================================
 */
bool sht31_probe(uint8_t addr) {
  Wire.beginTransmission(addr);
  Wire.write(0x37);
  Wire.write(0x80);
  if (Wire.endTransmission(false) != 0) return false;

  delay(1);

  uint8_t data[6];
  if (Wire.requestFrom(addr, (uint8_t)6) != 6) return false;

  for (int i = 0; i < 6; i++) data[i] = Wire.read();

  uint16_t sn1 = ((uint16_t)data[0] << 8) | data[1];
  uint16_t sn2 = ((uint16_t)data[3] << 8) | data[4];

  return (sn1 != 0x0000 || sn2 != 0x0000);
}

/*
 * ======================================================================================================================
 * sht45_probe()
 * =======================================================================================================================
 */
bool sht45_probe() {
  Adafruit_SHT4x sht4;
  return sht4.begin();
}

/*
 * ======================================================================================================================
 * bmp581_probe()
 * =======================================================================================================================
 */
bool bmp581_probe(uint8_t addr) {
  Wire.beginTransmission(addr);
  Wire.write(0x01);                    // CHIP_ID register = 0x50
  if (Wire.endTransmission(false) != 0) return false;

  if (Wire.requestFrom(addr, (uint8_t)1) != 1) return false;

  uint8_t chipid = Wire.read();
  return (chipid == 0x50);
}
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
